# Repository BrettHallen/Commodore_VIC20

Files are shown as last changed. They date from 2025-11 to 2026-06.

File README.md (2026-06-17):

# Commodore VIC-20 Hardware Projects
Hardware &amp; information for the VIC-20.<br>

## [MFJ-1258 Capacitance Meter](/MFJ-1258/)
By MFJ Enterprises<br>

## [HAMSOFT Cartridge](/HAMSOFT/)
By Kantronics<br>

## [VIKTRAK+ Software & AUTOTRAK Cartridge](/VIKTRAK/)
By K7NH/Neil Hill<br>

## [6560/6561 A/V Breakout Board](/VIC_6560/) - UNTESTED
The VIC's default video output is pretty bad.  I've long wanted to "go back to basics" and see how the output can be improved by, for example, wiring it up as per its original datasheet example circuit.<br>

The first step is to create this breakout board to isolate the A/V signals from the video output stage on the VIC's motherboard.<br>

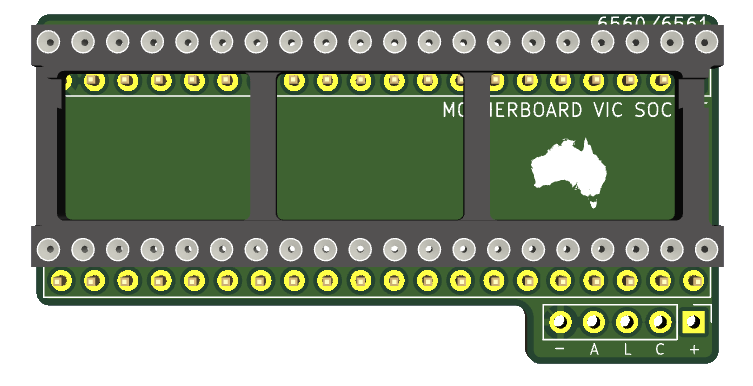
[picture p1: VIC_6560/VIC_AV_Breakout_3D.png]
3D view of breakout board


I hope that it will allow me to see what signals the 6560 outputs natively, then start to build on that.<br>

BTW, yes I know there are boards out there that already do this.  I've not had much luck with the free or paid-for boards, so I want to ... TRY TO ... understand it myself.  Let's see ...

## [6502 to W65C02S Daughterboard](/6502-to-65C02/) - UNTESTED
Unlike the 6522 VIAs that can be directly swapped for modern CMOS 65C22s from WDC, the W65C02S can't be directly swapped - a daughterboard is required to buffer the data bus signals and also handle some other signals/pins that differ.

3D view of 65C02S daughterboard

## [Serial Port Breakout Board for Logic Analysers](/Serial_Breakout_2)
I'm curious how JiffyDOS does its thing so whipped up a simple breakout board for the serial port so I can quickly and very easily connect up my logic analyser to capture the signalling with & without JiffyDOS.<br>

Connect the board to the VIC & the disc drive with a DIN-6, and then a 2x4 Dupont-style cable for the logic analyser.<br>

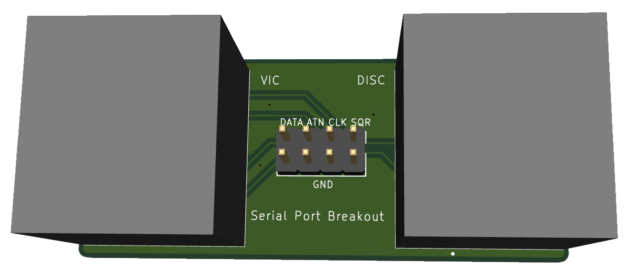
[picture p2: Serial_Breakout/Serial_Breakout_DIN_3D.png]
Serial breakout 3D


# RAM Expansions
Okay, my mind is full of ideas so it's probably a bit confusing with all these different designs.<br>

My original intent/idea was to replace the orignal ten 2114 RAM chips in case they were faulty.  It then grew from there.<br>

The different designs are:
- Original 8KB (BLK0) expansion: Replace the original 5KB plus 3KB expansion, switchable on/off via external switch.  This used a PLD which, in hindsight, is more complication than really needed.
- New 8KB expansion: Replace the PLD with the 74LS138, replicating the original VIC design but intercepting the ~RAM1/2/3 select signals.
- Simpler 8KB expansion: For a full BLK0 we really only need the ~BLK0 select signal so this greatly simplifies design but isn't switchable on/off.
- Full 32KB (BLK0/1/2/3) expansion
- Really Full 40KB (BLK0/1/2/3/5) expansion: Two designs to give the full 32+3KB expansion.  The Rev. A uses SMD and a larger SRAM and is, IMHO, overly complicated.  The Rev. B design is through-hole and piggybacks an 8KB (6264) SRAM on-top of the 32KB (62256) so we don't need to widen the board.

## [Orignal Internal 8KB RAM Expansion](/Internal_8KB/) - TESTED
My attempt to replace the VIC's built in 5KB of RAM (ten 2114 chips) with a single 8KB chip, with an extra 3KB RAM as a free bonus.

3D view of RAM upgrade board

## [New Internal 8KB RAM Expansion](/Internal_8KB_New/) - DESIGN
Removes the PLD and re-uses the 74LS138.

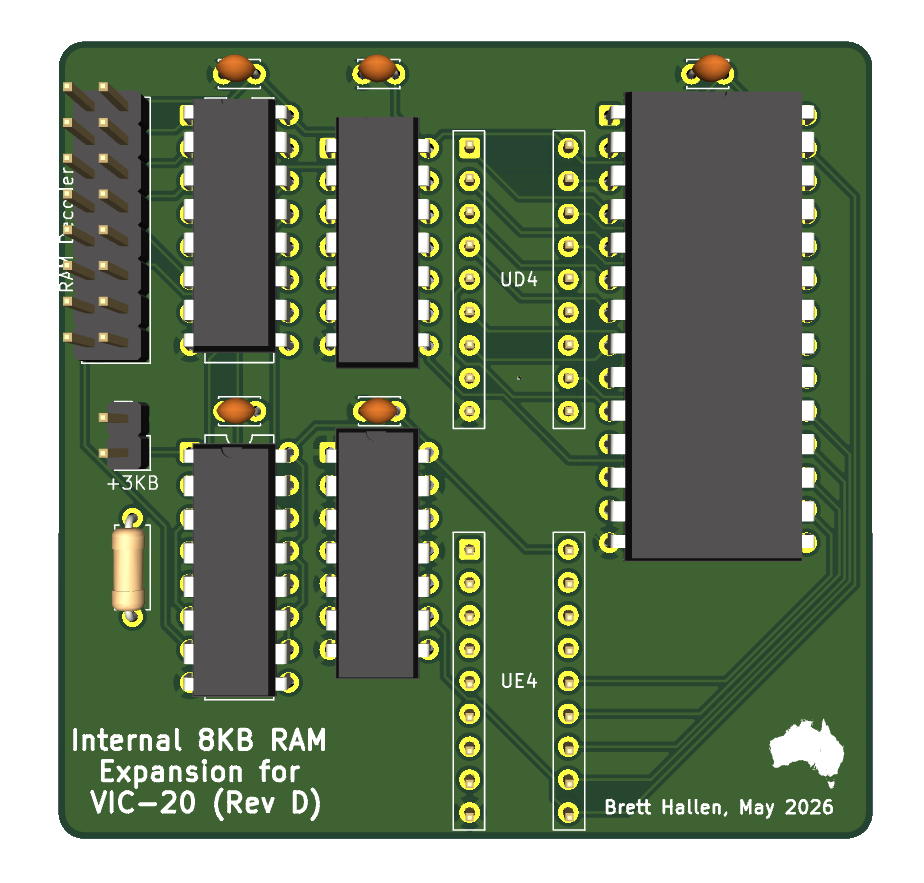
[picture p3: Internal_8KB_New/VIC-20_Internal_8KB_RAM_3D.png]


## [Simpler Internal 8KB RAM Expansion](/Internal_8KB_Simple/) - DESIGN
Just the 8KB for BLK0, nothing else.  As simple as my simple mind can make it.

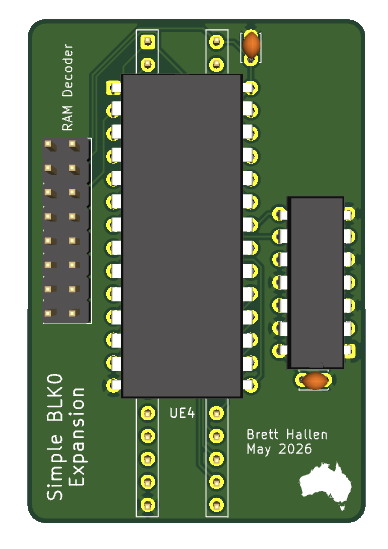
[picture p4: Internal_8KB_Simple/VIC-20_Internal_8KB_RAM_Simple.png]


## [Internal 40KB RAM Expansion](/Internal_40KB/) - DESIGNED
I've obsoleted the 32KB design and gone for this: the full 32KB of RAM in BLK0/1/2/3 plus an addition 8KB RAM or ROM in BLK5.<br>

The BLK1/2/3/5 are switchable off externally for software compatibility, and the BLK5 can be filled with either a 6264 SRAM or 2764/2864 (E)EPROM.  There is a header to switch whether it is writable (RAM) or not (ROM).<br>

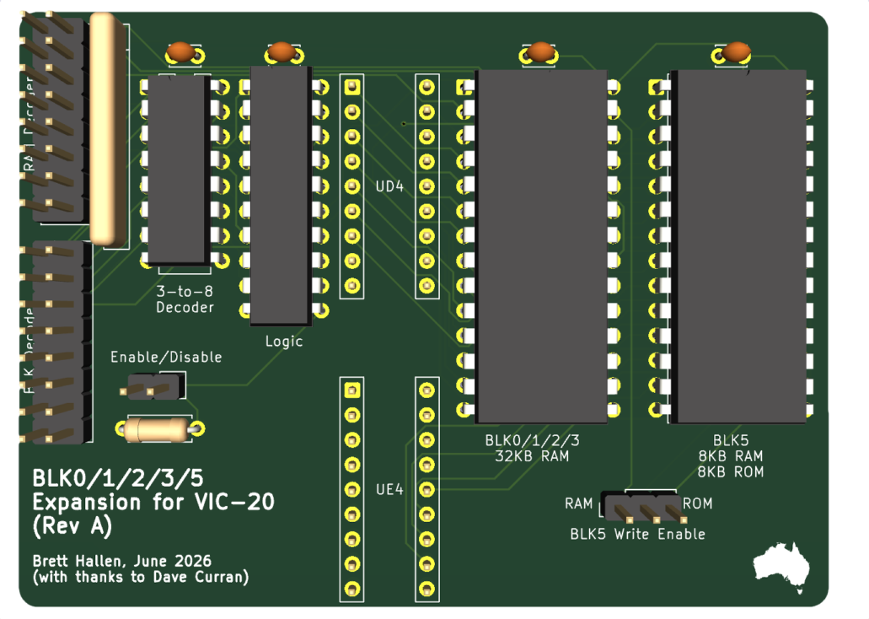
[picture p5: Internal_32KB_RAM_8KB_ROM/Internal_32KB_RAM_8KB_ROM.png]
The final boss of internal RAM expansions


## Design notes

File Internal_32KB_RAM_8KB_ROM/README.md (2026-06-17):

# Internal BLJK0/1/2/3/5 Expansion
My attempt to create a FAT VIC with a full 32KB internal RAM in BLK0/1/2/3 and an additioanl 8KB ROM or RAM in BLK5 without need for an external cartridge.<br>

Requires two [DIP-16 breakout boards](https://github.com/BrettHallen/Conversion_Boards/tree/main/DIP-16_Breakout) to replace the 74LS138 decoders.<br>

## Status
26-May-2026: complete re-design of my original idea, pending farbication & testing
17-Jun-2026: further re-design completed, pending fabrication & testing

## Purpose
- Save having to source replacement 2114 chips in case RAM is faulty;
- Upgrade the internal RAM unexpanded 5KB to a full 32KB, but switchable from outside the case depending on software requirements;
- Reduce power consumption/waste heat generation;
- Use as a learning experience to understand how the VIC's memory works and using a PLD;
- 100% reversible, no cutting of tracks required.

## YouTube Videos
- [Simple KiCad For Simple Vintage Computer Hobbyists: Part 5 (VIC-20 RAM Expansion)](https://youtu.be/WQpgBGNAkP0)
- [Commodore VIC-20 Internal RAM Replacement: Part 1](https://youtu.be/0KduuzFBmz8)
- [Commodore VIC-20 Internal RAM Replacement: Part 2](https://youtu.be/WdcPidc4c6I)

## Important Note
This information is provided to you completely free - use at your own risk.<br>
It is assumed that you kind-of know what you're doing - it is tricky removing chips from the VIC-20 motherboard as the top-layer tracks can lift up if there is still solder attached, so please be very careful.<br>
I've been using the Japanese-made ENGINEER SS-03 solder sucker a lot lately and highly recommend it.<br>

## Design
The VIC's memory is allocated in eight 8KB blocks named BLK0 to BLK7.  The RAM is normally found in BLK0 to BLK3.
```
Unexpanded VIC Memory
BLK0
0000   0000 0000 0000 0000 RAM0
03FF   0000 0011 1111 1111

1000   0001 0000 0000 0000 
1FFF   0001 1111 1111 1111 RAM4-7

Expanded VIC Memory
BLK0 (+3KB)
0400    0000 0100 0000 0000 RAM1
07FF    0000 0111 1111 1111

0800    0000 1000 0000 0000 RAM2
0BFF    0000 1011 1111 1111

0C00    0000 1100 0000 0000 RAM3
0FFF    0000 1111 1111 1111

BLK1 (+8KB)
2000    0010 0000 0000 0000
3FFF    0011 1111 1111 1111

BLK2 (+16KB)
4000    0100 0000 0000 0000
5FFF    0101 1111 1111 1111

BLK3 (+24KB)
6000    0110 0000 0000 0000
7FFF    0111 1111 1111 1111

BLK4 (Character ROM, VIC, VIAs, I/O, Colour RAM)
8000
9FFF

BLK5 (8KB ROM or RAM)
A000
BFFF

BLK6 (BASIC)
C000
DFFF

BLK7 (Kernal/Kernel)
E000
FFFF
```

[Commodore VIC-20 Memory Map](https://vic20reloaded.com/commodore-vic-20-memory-map/)

The daughterboard is designed to plug in to the VIC's motherboard where two of the original 2114 chips were located - expectation is that all ten 2114 chips are removed, and two replaced with an IC socket. <br>

The two 74LS138 decoders on the VIC motherboard are also removed and replaced with breakouts so the signals can be handled on the expansion daughterboard.<br>

### BLK0 Expansion
In order to fill in the missing 3KB in BLK0 we need to intercept the ~RAM1, ~RAM2 and ~RAM3 select signals and direct them to our RAM.<br>

This is done by relocating the 74LS138 to the expansion daughterboard and using all ~RAMx select signals for our RAM.<br>

### BLK1/2/3 Expansion
We should be able to fill in the BLK1/2/3 RAM by intercepting the associated ~BLK1, ~BLK2 and ~BLK3 select signals from the BLK decoder and using as the select signal for our RAM.<br>

Importantly we want to also be able to disable this additional RAM to allow software designed for the unexpanded/+3KB expanded VIC-20 to work correctly.  This can be done by connecting the ~BLK0/~BLK1/~BLK2 select signals via a multiplexor connected to an external switch that determines if the ~BLK1/2/3 select signals are passed back to the VIC or not.<br>

### BLK5 Expansion
This can have RAM or ROM, but the RAM isn't accessible from BASIC as it needs to be contiguous (BLK4 is in the way).  One possible use is to include the Super Expander ROM on the board.<br>

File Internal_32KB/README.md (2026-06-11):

# Internal 32KB RAM Expansion
My attempt to create a FAT VIC with a full 32KB internal RAM expansion without need for an external cartridge.<br>

Requires two [DIP-16 breakout boards](https://github.com/BrettHallen/Conversion_Boards/tree/main/DIP-16_Breakout) to replace the 74LS138 decoders.<br>

## Status
26-May-2026: complete re-design of my original idea, pending farbication & testing
11-Jun-2026: tested the re-design, it's "working" but has screen memory issues, fixed in next revision

## Purpose
- Save having to source replacement 2114 chips in case RAM is faulty;
- Upgrade the internal RAM unexpanded 5KB to a full 32KB, but switchable from outside the case depending on software requirements;
- Reduce power consumption/waste heat generation;
- Use as a learning experience to understand how the VIC's memory works and using a PLD;
- 100% reversible, no cutting of tracks required.

## YouTube Videos
- [Simple KiCad For Simple Vintage Computer Hobbyists: Part 5 (VIC-20 RAM Expansion)](https://youtu.be/WQpgBGNAkP0)
- [Commodore VIC-20 Internal RAM Replacement: Part 1](https://youtu.be/0KduuzFBmz8)
- [Commodore VIC-20 Internal RAM Replacement: Part 2](https://youtu.be/WdcPidc4c6I)

## Important Note
This information is provided to you completely free - use at your own risk.<br>
It is assumed that you kind-of know what you're doing - it is tricky removing chips from the VIC-20 motherboard as the top-layer tracks can lift up if there is still solder attached, so please be very careful.<br>
I've been using the Japanese-made ENGINEER SS-03 solder sucker a lot lately and highly recommend it.<br>

## Design
The VIC's memory is allocated in eight 8KB blocks named BLK0 to BLK7.  The RAM is normally found in BLK0 to BLK3.
```
Unexpanded VIC Memory
BLK0
0000   0000 0000 0000 0000 RAM0
03FF   0000 0011 1111 1111

1000   0001 0000 0000 0000 
1FFF   0001 1111 1111 1111 RAM4-7

Expanded VIC Memory
BLK0 (+3KB)
0400    0000 0100 0000 0000 RAM1
07FF    0000 0111 1111 1111

0800    0000 1000 0000 0000 RAM2
0BFF    0000 1011 1111 1111

0C00    0000 1100 0000 0000 RAM3
0FFF    0000 1111 1111 1111

BLK1 (+8KB)
2000    0010 0000 0000 0000
3FFF    0011 1111 1111 1111

BLK2 (+16KB)
4000    0100 0000 0000 0000
5FFF    0101 1111 1111 1111

BLK3 (+24KB)
6000    0110 0000 0000 0000
7FFF    0111 1111 1111 1111
```

[Commodore VIC-20 Memory Map](https://vic20reloaded.com/commodore-vic-20-memory-map/)

The daughterboard is designed to plug in to the VIC's motherboard where two of the original 2114 chips were located - expectation is that all ten 2114 chips are removed, and two replaced with an IC socket. <br>

The two 74LS138 decoders on the VIC motherboard are also removed and replaced with breakouts so the signals can be handled on the expansion daughterboard.<br>

### BLK0 Expansion
In order to fill in the missing 3KB in BLK0 we need to intercept the ~RAM1, ~RAM2 and ~RAM3 select signals and direct them to our RAM.<br>

This is done by relocating the 74LS138 to the expansion daughterboard and using all ~RAMx select signals for our RAM.<br>

### BLK1/2/3 Expansion
We should be able to fill in the BLK1/2/3 RAM by intercepting the associated ~BLK1, ~BLK2 and ~BLK3 select signals from the BLK decoder and using as the select signal for our RAM.<br>

Importantly we want to also be able to disable this additional RAM to allow software designed for the unexpanded/+3KB expanded VIC-20 to work correctly.  This can be done by connecting the ~BLK0/~BLK1/~BLK2 select signals via a multiplexor connected to an external switch that determines if the ~BLK1/2/3 select signals are passed back to the VIC or not.<br>

### CPU vs VIC RAM Access
The CPU (6502) and VIC (6560/6561) share access to the RAM, alternating depending on the state of the SΦ2 clock.  When the clock is high the CPU is accessing the RAM and when the clock is low it is the VIC's turn.<br>

Importantly the screen memory is in BLK0 and thus A13 and A14 are low.  My design failed to account for this and this results in the VIC accessing anywhere in the BLK0 to BLK3 range depending on what the status of A13 and A14 was.  I have improved the design to account for this, to be tested.

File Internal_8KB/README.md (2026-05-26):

# Internal 8KB RAM Expansion
My attempt to create a simple internal RAM upgrade board for the original VIC-20 (two-prong power, not the CR).  And, I'm not touching the single 2114 used for the colour RAM.<br>

## UPDATE 26-MAY-2026
I've [redesigned](/Internal_8KB_New) the 8KB expansion based on my 32KB design.<br>

## Purpose
- Save having to source replacement 2114 chips in case RAM is faulty;
- Upgrade the internal RAM from 5KB to 8KB, filling BLK0, but make it switchable ON/OFF from outside the case;
- Reduce power consumption/waste heat generation (reduced by just over 200mA, almost 20%);
- Use as a learning experience to understand how the VIC's memory works and using a PLD;
- 100% reversible, no cutting of tracks or soldering of wires to chip legs required.

## YouTube Videos
- [Simple KiCad For Simple Vintage Computer Hobbyists: Part 5 (VIC-20 RAM Expansion)](https://youtu.be/WQpgBGNAkP0)
- [Commodore VIC-20 Internal RAM Replacement: Part 1](https://youtu.be/0KduuzFBmz8)

## Important Note
This information is provided to you completely free - use at your own risk.<br>
It is assumed that you kind-of know what you're doing - it is tricky removing chips from the VIC-20 motherboard as the top-layer tracks can lift up if there is still solder attached, so please be very careful.<br>
I've been using the Japanese-made ENGINEER SS-03 solder sucker a lot lately and highly recommend it.<br>

## Design
This is the layout of the VIC's BLK0 (first 8KB chunk of memory):
```
1KB LOW (Zero Page)
0000-03FF   0000 0000 0000 0000 A10-A12 = 0
            0000 0011 1111 1111

3KB EXPANSION CARTRIDGE
0400-07FF   0000 0100 0000 0000 !RAM1  (A10)
            0000 0111 1111 1111
0800-0BFF   0000 1000 0000 0000 !RAM2  (A11)
            0000 1011 1111 1111
0C00-0FFF   0000 1100 0000 0000 !RAM3  (A10+A11)
            0000 1111 1111 1111

4KB MAIN
1000-1FFF   0001 0000 0000 0000 A12
            0001 0011 1111 1111 
            0001 0100 0000 0000 A10+A12
            0001 0111 1111 1111
            0001 1000 0000 0000 A11+A12
            0001 1011 1111 1111
            0001 1100 0000 0000 A10+A11+A12
            0001 1111 1111 1111
```

As per the existing VIC RAM design, we only want the RAM chip select to be active for these conditions:
- VA13 = high (when low the character ROM is selected), and
- BLK0 = low

All other combinations we want RAM chip select to be inactive.

Additionally, we want to be able to disable the full 8KB and return the VIC to its original "unexpanded VIC" state to avoid possible software compatibility issues.  The original 5KB of RAM is accessed when:
- A12 = high, or
- A10, A11, A12 = low

In its unexpanded state we should ignore all other combinations of A10 to A12.

The daughterboard is designed to plug in to the VIC's motherboard where two of the original 2114 chips were located - expectation is that all ten 2114 chips are removed, and two replaced with an IC socket.

The board itself is quite simple, using just the 6264 RAM chip and a PLD chip for the chip select logic.<br>

In order for the additional 3KB expansion to work we need to remove the 74LS138 RAM decoder (UC4 on my board) - its logic will be replaced by that in the PLD.<br>

Some wires need to be connected from the RAM board to where the [RAM decoder](/Internal_8KB/Images/VIC-20_internal_RAM_layout.jpg) was to pick up required signals:<br>
- VA10 from UC4 pin 1
- VA11 from UC4 pin 2
- VA12 from UC4 pin 3
- VA13 from UC4 pin 6
- /BLK0 from UC4 pin 4
- /RAM1 to UC4 pin 12
- /RAM2 to UC4 pin 13
- /RAM3 to UC4 pin 14

Note that all of these are connected using the additonal 74LS138 daughterboard.  Simply plug an 8-way cable set into the pin headers on the RAM and 74LS138 boards and the connections are done!<br>

## BOM
- 6264 SRAM
- GAL16V8 (i.e. Atmel F16V8B)
- 10KΩ pull-up resistor
- 2 x 100nF decoupling capacitor
- 2 x 18-pin DIP sockets (for UD4 & UE4 RAM locations)
- 4 x 9-pin SIL two-way pin headers (to plug into DIP sockets)
- 2 x 8-way pin header (for extra required signals)
- 2-way pin header (for 3KB expansion disable/enable)
- 1 x 16-pin DIP socket (for UC4 RAM decoder location)
- 8-way Dupont connector wiring

## Status
25-Apr-2025: Initial design done, checking-over before sending to PCBWAY for fabrication<br>
10-May-2025: Test PCB built & being tested<br>
11-May-2025: IT WORKS!  But, some small revisions to the board are required ...<br>
12-May-2025: Revisions to board made, new 74LS138 daughterboard created, might still tweak the design a little<br>
13-May-2025: I've decided to go all the way and create a 32KB expansion, still switchable from outside the case.<br>
15-May-2025: Sent revised 8KB and new 32KB boards for fabrication.<br>

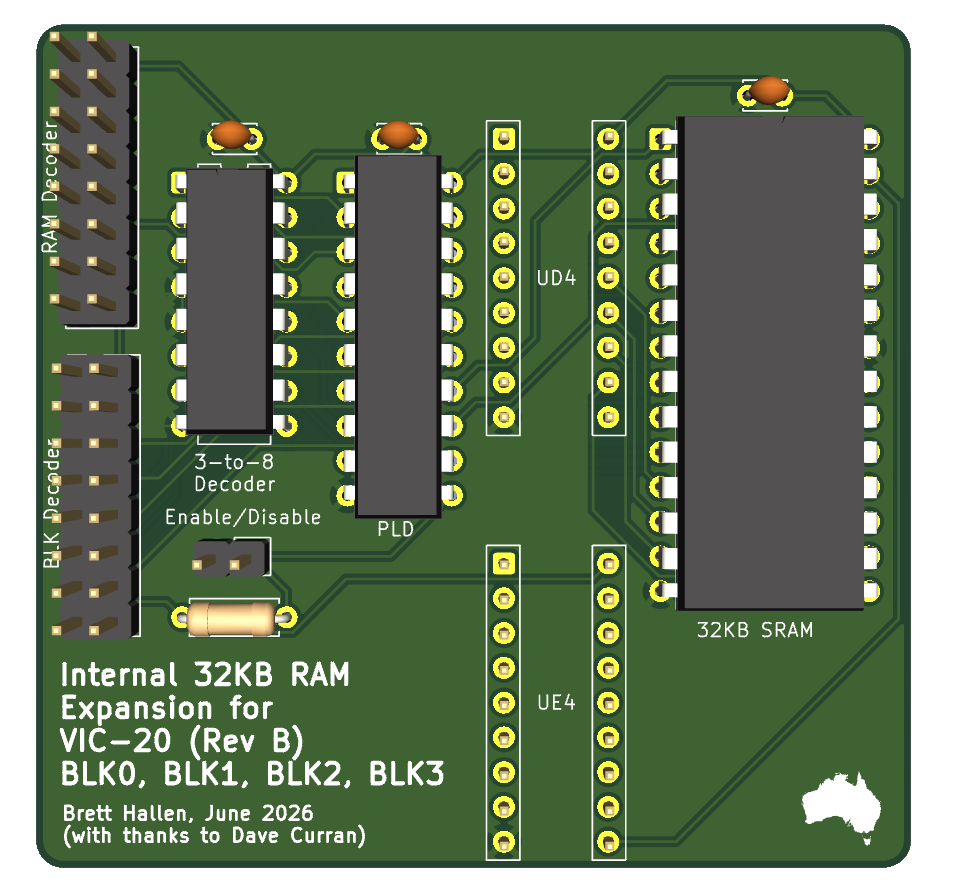
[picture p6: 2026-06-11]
Internal_32KB/VIC-20_Internal_32KB_3D.png

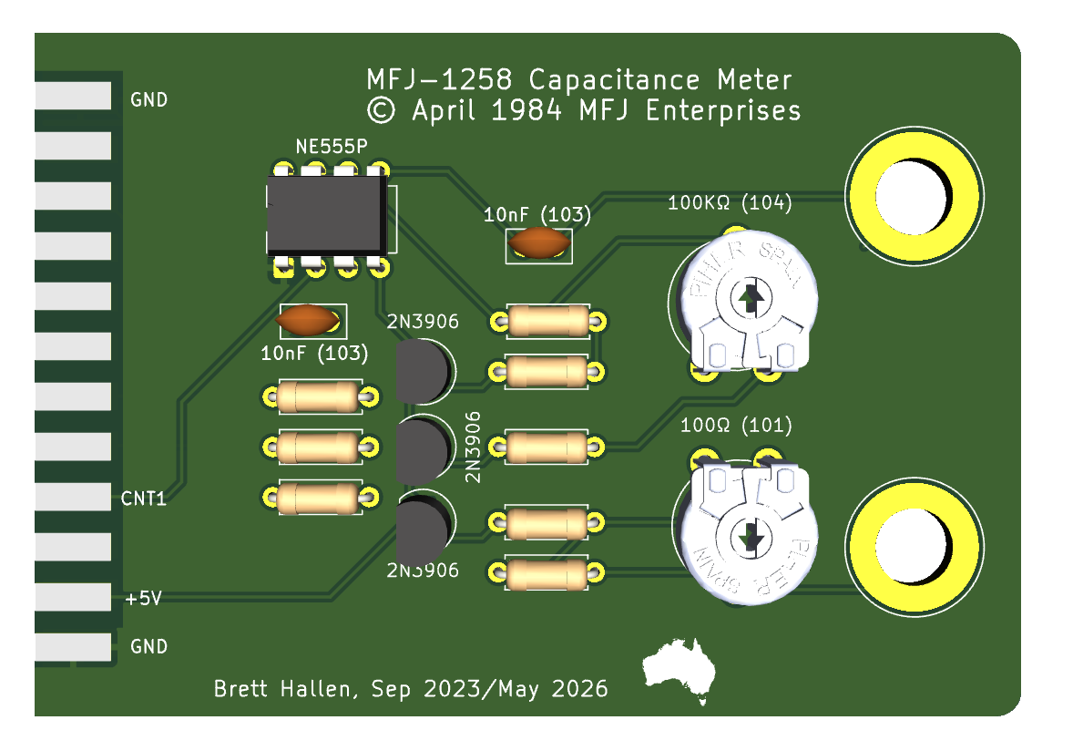
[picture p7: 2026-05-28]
MFJ-1258/Redrawn_MFJ-1258_Board.png

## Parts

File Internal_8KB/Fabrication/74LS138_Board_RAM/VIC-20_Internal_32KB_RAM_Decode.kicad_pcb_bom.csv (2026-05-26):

Designator | Quantity | Value | Footprint | Package | MPN | DNP | Mount_Type | Description
J1 | 1 | Signals | PinHeader_1x08_P2.54mm_Vertical |  |  |  | tht | Generic connector, single row, 01x08, script generated (kicad-library-utils/schlib/autogen/connector/)
UC4 | 1 | 74LS138 | DIP-16_W7.62mm |  |  |  | tht | Generic connector, double row, 02x08, counter clockwise pin numbering scheme (similar to DIP package numbering), script generated (kicad-library-utils/schlib/autogen/connector/)

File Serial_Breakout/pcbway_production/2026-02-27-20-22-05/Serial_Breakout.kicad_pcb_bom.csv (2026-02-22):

Designator | Quantity | Value | Footprint | Package | MPN | DNP | Mount_Type | Description | Height | Manufacturer_Name
J1 | 1 | VIC Serial In | 6710601 |  | 671-0601 |  | tht | Deltron 6 Pole Right Angle Din Socket Socket, 2A, 100 V ac, Lockable | 19.5 | DELTRON COMPONENTS
J2 | 1 | Disc Serial Out | 6710601 |  | 671-0601 |  | tht | Deltron 6 Pole Right Angle Din Socket Socket, 2A, 100 V ac, Lockable | 19.5 | DELTRON COMPONENTS
J3 | 1 | Breakout | PinHeader_2x04_P2.54mm_Vertical |  |  |  | tht | Generic connector, double row, 02x04, odd/even pin numbering scheme (row 1 odd numbers, row 2 even numbers), script generated (kicad-library-utils/schlib/autogen/connector/)

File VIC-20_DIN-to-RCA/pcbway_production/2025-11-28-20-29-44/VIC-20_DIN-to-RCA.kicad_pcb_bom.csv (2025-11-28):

Designator | Quantity | Value | Footprint | Package | MPN | DNP | Mount_Type | Description | Height | Manufacturer_Name | Mouser Part Number | Mouser Price/Stock
J1 | 1 | VIC-20 Composite | 6710801 |  | 671-0801 |  | tht | Deltron 8 Pole Right Angle Din Socket Socket, 2A, 100 V ac, Lockable | 19.5 | DELTRON COMPONENTS
J2 | 1 | RCA Video | FC68371 |  | FC68371 |  | tht | Socket; RCA; female; angled 90; THT; nickel plated; Marker: black | 14 | CLIFF ELECTRONIC COMPONENTS
J3 | 1 | Audio Out | SJ3350820BTR |  | SJ3-350820B-TR |  | tht | 3.5 mm Stereo Jack, Through Hole, 2 Conductors, 1 Internal Switches, Tape & Reel Packaging | 5.3 | Same Sky | 179-SJ3-350820B-TR | https://www.mouser.co.uk/ProductDetail/Same-Sky/SJ3-350820B-TR?qs=IKkN%2F947nfBCsohFK16iQg%3D%3D

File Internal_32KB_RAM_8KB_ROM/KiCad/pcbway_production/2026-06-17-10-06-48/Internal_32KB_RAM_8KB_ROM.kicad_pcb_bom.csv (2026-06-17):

Designator | Quantity | Value | Footprint | Package | MPN | DNP | Mount_Type | Description
C1, C2, C3, C4 | 4 | 100nF | C_Disc_D3.0mm_W2.0mm_P2.50mm |  |  |  | tht | Unpolarized capacitor
J1 | 1 | UD4 | DIP-18_W7.62mm |  |  |  | tht | Generic connector, double row, 02x09, counter clockwise pin numbering scheme (similar to DIP package numbering), script generated (kicad-library-utils/schlib/autogen/connector/)
J2 | 1 | UE4 | DIP-18_W7.62mm |  |  |  | tht | Generic connector, double row, 02x09, counter clockwise pin numbering scheme (similar to DIP package numbering), script generated (kicad-library-utils/schlib/autogen/connector/)
J3 | 1 | RAM Decoder | PinHeader_2x08_P2.54mm_Vertical |  |  |  | tht | Generic connector, double row, 02x08, counter clockwise pin numbering scheme (similar to DIP package numbering), script generated (kicad-library-utils/schlib/autogen/connector/)
J4 | 1 | BLK Decoder | PinHeader_2x08_P2.54mm_Vertical |  |  |  | tht | Generic connector, double row, 02x08, counter clockwise pin numbering scheme (similar to DIP package numbering), script generated (kicad-library-utils/schlib/autogen/connector/)
J5 | 1 | Disable/Enable Switch | PinHeader_1x02_P2.54mm_Vertical |  |  |  | tht | Generic connector, single row, 01x02, script generated (kicad-library-utils/schlib/autogen/connector/)
J6 | 1 | BLK5 Write Enable | PinHeader_1x03_P2.54mm_Vertical |  |  |  | tht | Generic connector, single row, 01x03, script generated (kicad-library-utils/schlib/autogen/connector/)
R1 | 1 | 10KΩ | R_Axial_DIN0207_L6.3mm_D2.5mm_P7.62mm_Horizontal |  |  |  | tht | Resistor
RN1 | 1 | 10KΩ | R_Array_SIP9 |  |  |  | tht | 8 resistor network, star topology, bussed resistors, small symbol
U1 | 1 | ATF16V8 | DIP-20_W7.62mm |  |  |  | tht | High-performance EE PLD, PAL Device Emulation / PAL Replacement, DIP-20
U2 | 1 | 74HCT138 | DIP-16_W7.62mm |  |  |  | tht | 3-to-8 line decoder/multiplexer inverting, DIP-16/SOIC-16/SSOP-16
U3 | 1 | 62256 | DIP-28_W15.24mm |  |  |  | tht | 32,768-word × 8-bit High Speed CMOS Static RAM, 70ns, DIP-28
U4 | 1 | 2864 | DIP-28_W15.24mm |  |  |  | tht | EEPROM 8K x 8, 5V, Not in Production, DIP-28

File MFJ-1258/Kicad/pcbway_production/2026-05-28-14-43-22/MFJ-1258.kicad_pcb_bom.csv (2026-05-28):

Designator | Quantity | Value | Footprint | Package | MPN | DNP | Mount_Type
C1, C2 | 2 | 10nF (103) | C_Disc_D5.0mm_W2.5mm_P2.50mm |  |  |  | tht
J1 | 1 | C64-UserPort | C64-User-Port-Female |  |  |  | smt
J2, J3 | 2 | Screw_Terminal_01x01 | Banana_Jack_1Pin |  |  |  | tht
Q1, Q2, Q3 | 3 | 2N3906 | TO-92_Inline |  |  |  | tht
R1 | 1 | 510Ω | R_Axial_DIN0207_L6.3mm_D2.5mm_P7.62mm_Horizontal |  |  |  | tht
R2 | 1 | 1.2MΩ | R_Axial_DIN0207_L6.3mm_D2.5mm_P7.62mm_Horizontal |  |  |  | tht
R3, R4, R5 | 3 | 4.7KΩ | R_Axial_DIN0207_L6.3mm_D2.5mm_P7.62mm_Horizontal |  |  |  | tht
R6 | 1 | 5.6MΩ | R_Axial_DIN0207_L6.3mm_D2.5mm_P7.62mm_Horizontal |  |  |  | tht
R7 | 1 | 3.9MΩ | R_Axial_DIN0207_L6.3mm_D2.5mm_P7.62mm_Horizontal |  |  |  | tht
R8 | 1 | 330Ω | R_Axial_DIN0207_L6.3mm_D2.5mm_P7.62mm_Horizontal |  |  |  | tht
RV1 | 1 | 100Ω (101) | Potentiometer_Piher_PT-10-V10_Vertical |  |  |  | tht
RV2 | 1 | 100KΩ (104) | Potentiometer_Piher_PT-10-V10_Vertical |  |  |  | tht
U1 | 1 | NE555P | DIP-8_W7.62mm |  |  |  | tht

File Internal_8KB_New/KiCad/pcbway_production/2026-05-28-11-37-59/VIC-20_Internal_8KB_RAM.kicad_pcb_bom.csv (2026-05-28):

Designator | Quantity | Value | Footprint | Package | MPN | DNP | Mount_Type | Description
C1, C2, C3, C4, C5 | 5 | 100nF | C_Disc_D3.0mm_W2.0mm_P2.50mm |  |  |  | tht | Unpolarized capacitor
J1 | 1 | RAM Decoder | PinHeader_2x08_P2.54mm_Vertical |  |  |  | tht | Generic connector, double row, 02x08, counter clockwise pin numbering scheme (similar to DIP package numbering), script generated (kicad-library-utils/schlib/autogen/connector/)
J2 | 1 | UD4 | DIP-18_W7.62mm |  |  |  | tht | Generic connector, double row, 02x09, counter clockwise pin numbering scheme (similar to DIP package numbering), script generated (kicad-library-utils/schlib/autogen/connector/)
J3 | 1 | UE4 | DIP-18_W7.62mm |  |  |  | tht | Generic connector, double row, 02x09, counter clockwise pin numbering scheme (similar to DIP package numbering), script generated (kicad-library-utils/schlib/autogen/connector/)
J4 | 1 | +3KB | PinHeader_1x02_P2.54mm_Vertical |  |  |  | tht | Generic connector, single row, 01x02, script generated (kicad-library-utils/schlib/autogen/connector/)
R1 | 1 | 10KΩ | R_Axial_DIN0207_L6.3mm_D2.5mm_P7.62mm_Horizontal |  |  |  | tht | Resistor
U1 | 1 | 74HCT04 | DIP-14_W7.62mm |  |  |  | tht | Hex Inverter
U2 | 1 | 74HCT138 | DIP-16_W7.62mm |  |  |  | tht | Decoder 3 to 8 active low outputs
U3 | 1 | 74HCT30 | DIP-14_W7.62mm |  |  |  | tht | 8-input NAND
U4 | 1 | 74HCT157 | DIP-16_W7.62mm |  |  |  | tht | Quad 2 to 1 line Multiplexer
U5 | 1 | 6264 SRAM | DIP-28_W15.24mm |  |  |  | tht | Not in Production, 8Kx8 bit Static RAM, 70/85/100/120/150ns, DIP-28

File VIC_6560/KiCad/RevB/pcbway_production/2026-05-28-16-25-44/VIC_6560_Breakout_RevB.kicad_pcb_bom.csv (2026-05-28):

Designator | Quantity | Value | Footprint | Package | MPN | DNP | Mount_Type | Description
J1 | 1 | MOTHERBOARD VIC SOCKET | DIP-40_W15.24mm |  |  |  | tht | Generic connector, double row, 02x20, counter clockwise pin numbering scheme (similar to DIP package numbering), script generated (kicad-library-utils/schlib/autogen/connector/)
J2 | 1 | BREAKOUT_PINS | PinHeader_1x05_P2.54mm_Vertical |  |  |  | tht | Generic connector, single row, 01x05, script generated (kicad-library-utils/schlib/autogen/connector/)
U1 | 1 | 6560/6561 | DIP-40_W15.24mm |  |  |  | tht

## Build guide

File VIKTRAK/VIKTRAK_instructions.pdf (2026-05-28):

VIKTRAK+ DISTRIBUTED BY | Retyped by
SPECTRUM WEST | Brett Hallen, Nov 2024
?717 N.E. 56th | YouTube.com/@Brfff
Seattle, WA 98150

VIKTRAK+ is a satellite tracking program for the VIC20 with three or more kilobytes of additional memory (see note 1),

MAIN FEATURES
1. This program is easy to use, fast, and colourful.
2. Handles both elliptical and circular satellites.
3. Provides satellite location with a blinking cursor on a World Map.
Provides bearing and elevation to satellite if it is within range.
4. Output to a printer is provided for hardcopy of data.
5. A software routine is built in to operate an automatic antenna aiming system.

STARTING OUT
"LOAD” the program into the computer using normal tape loading procedure. The program starts at 5 on the tape counter and takes about two minutes. A second copy of the program is at 50 on the counter.

After the tape is loaded you need to put in your home latitude (HT) and home Longitude (HN). Type in LIST 150 and press RETURN. Use normal VIC editing techniques to enter your latitude and longitude. At this time it would be wise to get a clean cassette and make an operating copy of this program. To do so enter RUN and press RETURN. A MENU will appear. Press “D” (SAVE PGM) and start recording on your clean cassette. Take the original cassette of VIKTRAK+ and put it in a safe place as a permanent backup copy. If you hate to read instructions, now is the time to put this aside and play with the program. Just follow screen instructions. If you should drop out of the program just enter RUN and press RETURN to get back to the MENU.

HOW TO USE THE PROGRAM
The MENU gives you four choices. The main section, “Tracking,” is entered by pressing “A”. Next will follow three requests. First enter the date you desire, using the example, incorrect format cannot be processed so a “?” will appear meaning try again. Next you will be asked which satellite you want. A list of satellites available is provided on the screen. The program will only accept these as choices, otherwise a “?” will appear. Lastly the UTC time will be asked for. Times from 0000 to 2359 UTC will be accepted, otherwise the “?” will appear again. When these three requests are fulfilled a World Map will be drawn on the screen with a blinking cursor showing satellite location, name of satellite, date, time, satellite longitude and latitude will also be shown, as well as bearing and elevation IF the satellite is within range. Orbit PHASE is included for elliptical satellites. The program is designed to run in real time, updating itself each six minutes for elliptical satellites and two minutes for circular ones. Manual updating can be accomplished by pressing RETURN as often as you desire. Several choices are available at this time if so desired and are noted at the top of the screen. Here is how they work.
A=AOS will cause the program to leave real time and calculate the next Acquisition of Signal time. It may take a while, so relax. The length of time depends on which satellite is being tracked and how long it is to AOS.

N=NEW SAT allows you to switch satellites at will. You will be asked for what UTC time you desire for this new satellite.
M=MENU returns you to the start of the program. You should do this whenever you want to change dates.
T=TIME lets you change UTC time at will. The new data will appear in about two seconds.
P=PRINTER allows the screen data to be output to a printer. In this mode real time is bypassed and your printer will give new update information every five seconds or so. To exit this mode press “P” again right after a line is printed, it will revert to normal tracking mode.

One thing about the program should be noted. You can proceed into a new day and the date will change but if a new UTC time is requested the resulting data will be for the original date selected. Remember, return to the MENU whenever a new date is desired unless you leave the program in the automatic update mode.

Back to the menu choices:
Pressing “B” allows you to easily change satellite data. You will be asked for which satellite you want data. After entering this the program lines containing that satellite data will be listed on the screen. This data can be changed by the normal screen editing of the VIC20. Return to the MENY by entering RUN and pressing RETURN. Don’t forget to move the cursor out of the listing area before entering RUN as you may modify the program lines accidentally.
Pressing “C” brings up a screen page of frequency information for satellites available in the program.
Selecting “D” allows a quick and easy way to RESAVE the program after any data has been changed. Please don’t use this to make extra copies of this program for your friends. The program is copyrighted and besides the price is very reasonable. Telling them where to send for the program would be a honest help for your friends.

SATELLITE DATA UPDATES
This program uses a somewhat non-standard set of data to computer satellite location but this information is readily available from several sources such as WIAW bulletins, NASA, AMSAT nets, and AMATEUR SATELLITE REPORT published by AMSAT.

The first three numbers needed pertain to reference orbit information. A reference orbit is the first orbit of whatever reference day you choose.
DR is Day of Reference and is the day of the year. DR can be calculated by using the tracking program. When asked for the date you desire, enter the date of your reference data. Example: 04APR84. When the program ask for satellite name press RUN/STOP and RESTORE together. You will exit the program (and change screen colour). Now enter PRINT DY, and press RETURN. The number that appears is DR (Day Reference).
MR is Minutes of Reference. It is the time of apogee (for elliptical satellites) or equator crossing (for circular satellites) and is entered in minutes and tenths of minutes, example: 2 hrs 10 mins and 30 secs would be 130.5 minutes.
LR is Longitude Reference and is always west longitude. If a reference is given as east longitude just subtract it from 360. Example: 15 degrees east longitude would be 360-15, or 345 degrees west longitude.
Remember: DR is Day of Year, MR is in minutes, and LR is always in longitude west.

Elliptical satellites use first apogee for Reference Day, circular satellites use first EQX crossing of Reference Day.

There are six other pieces of data still needed - these are the Keplerian or orbital elements. They are:
PE - Nodal Period
LI - Longitude Increment West
W - Argument of Perigee (zero for circular satellites) I - Inclination
SE - Semimajor Axis
EC - Eccentricity

This information is available from AMATEUR SATELLITE REPORT, AMSAT nets (Tuesday, 8:00pm local, 3850 kHz) or NASA. Of these only one needs to be updated except rarely. Once a month or so for elliptical satellites update W (Argument of Perigee). At the same time put in new reference orbit data for those satellites you’re using. This should be often enough.

TO ADD NEW SATELLITES
As more satellites are put up you will want to add them to this program. A standard layout is used to store data. LIST 650-658 to see the layout for circular satellites, or LIST 800-894 for elliptical satellites. Use these as a pattern.

650 ON-(N$<>"RS5") GOTO 660:IF M$="B"THEN LIST 652-656
652 W=0:I=82.96:SE=8034:EC=0
654 PE=119.554:LI=30.02
656 DR=346:MR=16.4:LR=236.4
658 RETURN

800 ON-(N$<>"O10") GOTO 620:IF M$="B" THEN LIST802-806 802 I=26.35:SE=26106:EC=.597
804 PE=699.45:LI=175.42
806 DR=334:MR=582:LR=225:W=65
808 GOTO 890
890 MR=MR-PE/2:LR=LR+(360-LI)/2:IF MR<0 THEN MR=MR+PE:LR=LR+LI
892 IF LR>=360 THEN LR=LR-360
894 RETURN

Note lines 980-984 are needed to convert apogee data to the perigee data used by the program for elliptical satellites. These lines are not needed for circular satellites as perigee is set on the equator when W is zero. Don’t forget to add your new satellites name to line 610.

AUTOROTOR is a software routine designed to work into a plug-in board to interface with appropriate rotators for automatic antenna aiming. These boards should be available soon.

Any comments and/or suggestions would be appreciated. See you on the birds.

Note: 1. This program comes set up for 8K or more of extra memory. It can be used with 3K memory by making these changes:
Line 43, change 4404 to 7988
Line 44, change 33792 to 30720

43 U%=4404-INT((U+50)/10)*22:S%=S%+U%
44 POKE S%,96:POKE S%+33792,1:FOR L=1 TO 9:GET A$:ON-(A$<>"") GOTO 54:NEXT

FURTHER INFORMATION [NOV 2024] https://www.spaceacademy.net.au/watch/track/orbspec.htm

The position of an orbital space object can thus be specified by six parameters:
1. a - the semimajor axis specifies the size of the orbit
2. e - the eccentricity specifies the shape of the orbit
3. i - the inclination specifies one orientation of the orbit
4. ω - the argument of perigee specifies a 2nd orientation of the orbit
5. Ω - the argument of the ascending node specifies the 3rd oreientation
6. tp - the time of perigee passage is used to calculate the object location in the orbit

These parameters are sometimes referred to as the Keplerian elements of the orbit.

However, they are not the only way to specify the position of an object.

The US Strategic Command, which operates the US space tracking network issues space object orbital information in a form they call TLE (Two Line Elements) because the specified parameters are printed over two lines.

The actual six parameters used are a modification of the six elements we have used previously.

- n - the mean motion of the satellite in revolutions per day (this gives a)
- e - the orbital eccentricity (identical)
- i - the orbital inclination (identical)
- RAAN - the Right Ascension of the Ascending Node (this gives Ω)
- ω - the argument of perigee (identical)
- M - the mean anomaly at the time specified in the TLE and substitutes for the tp parameter
- D/T - date and time of the TLE

There is also a decay value included - which refers to orbital change due to atmospheric perturbation of the elements.

To calculate the satellite mean anomaly you subtract the the TLE time from the satellite prediction time and multiply the result by the mean motion n.

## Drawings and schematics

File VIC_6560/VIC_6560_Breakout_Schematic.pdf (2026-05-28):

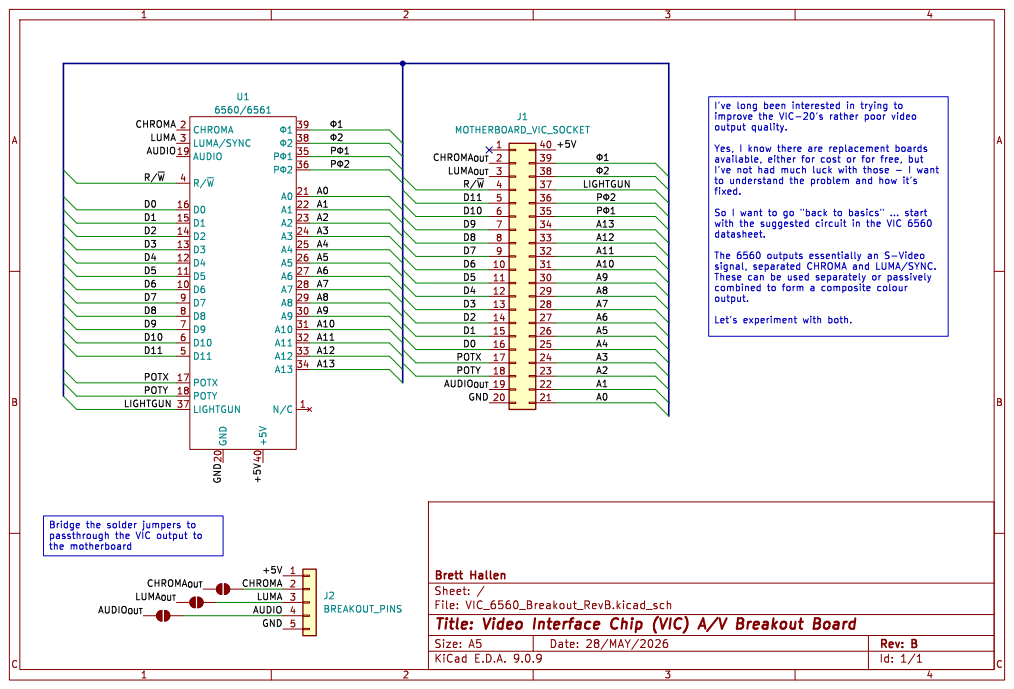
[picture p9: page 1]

I've not had much luck with those - I want
fixed.

Bridge the solder jumpers to
the motherboard

Sheet: /
File: VIC_6560_Breakout_RevB.kicad_sch
Title: Video Interface Chip (VIC) A/V Breakout Board

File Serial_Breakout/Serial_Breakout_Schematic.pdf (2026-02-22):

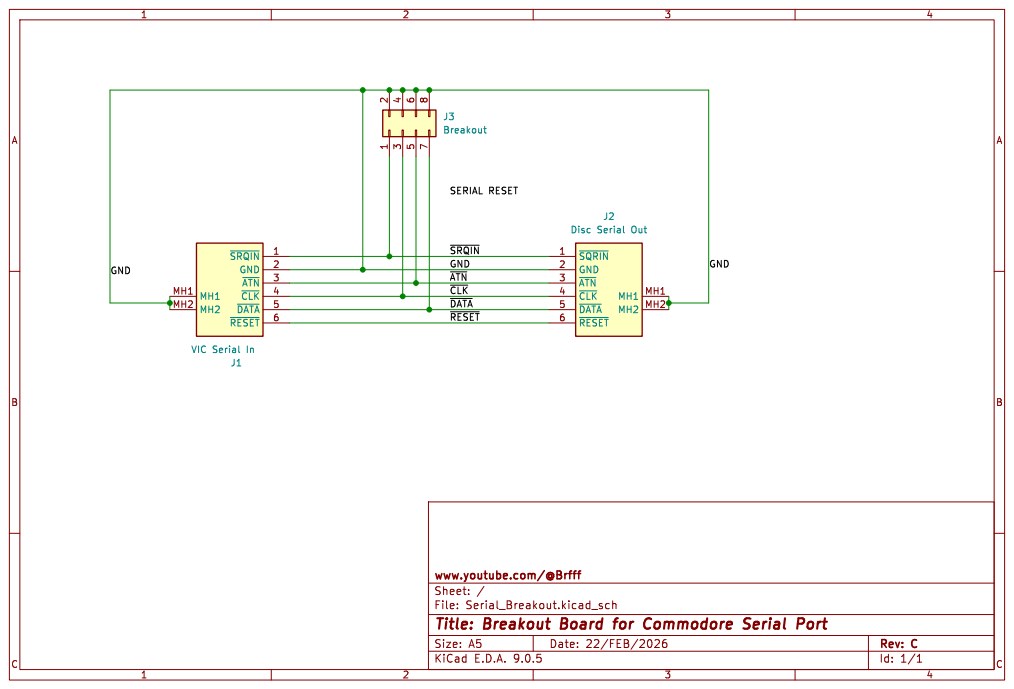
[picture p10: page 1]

GND | | GND 2 GND GND

~{ATN} | | ~{ATN} 3
~{CLK} | | ~{CLK} 4

www.youtube.com/@Brfff
Sheet: /
File: Serial_Breakout.kicad_sch
Title: Breakout Board for Commodore Serial Port

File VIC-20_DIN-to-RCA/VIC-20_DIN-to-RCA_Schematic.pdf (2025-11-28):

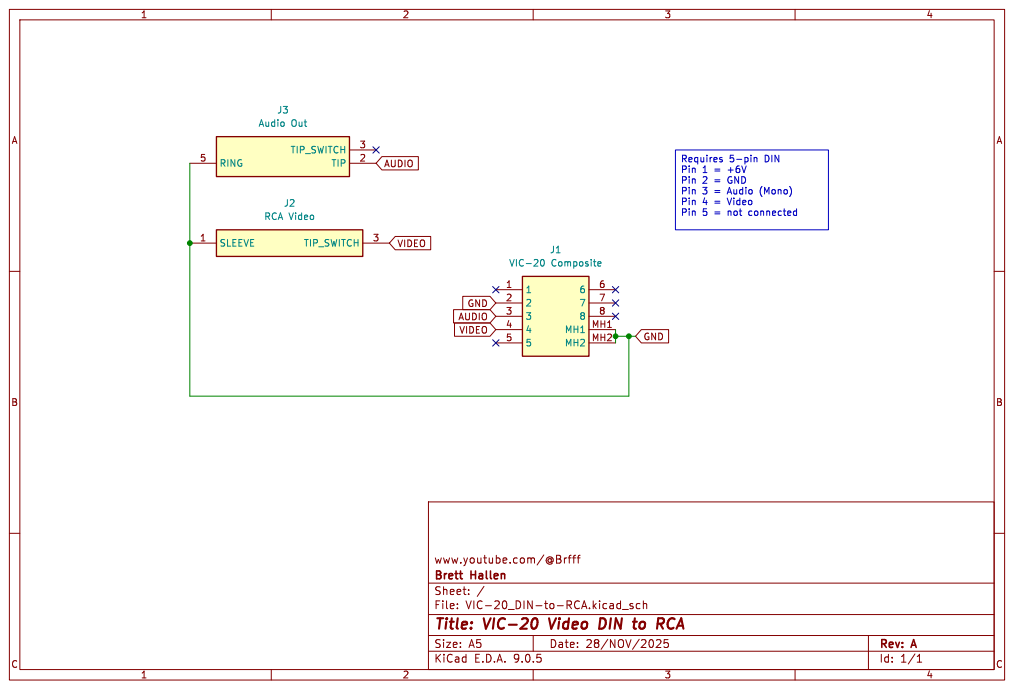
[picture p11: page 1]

www.youtube.com/@Brfff
Sheet: /
File: VIC-20_DIN-to-RCA.kicad_sch

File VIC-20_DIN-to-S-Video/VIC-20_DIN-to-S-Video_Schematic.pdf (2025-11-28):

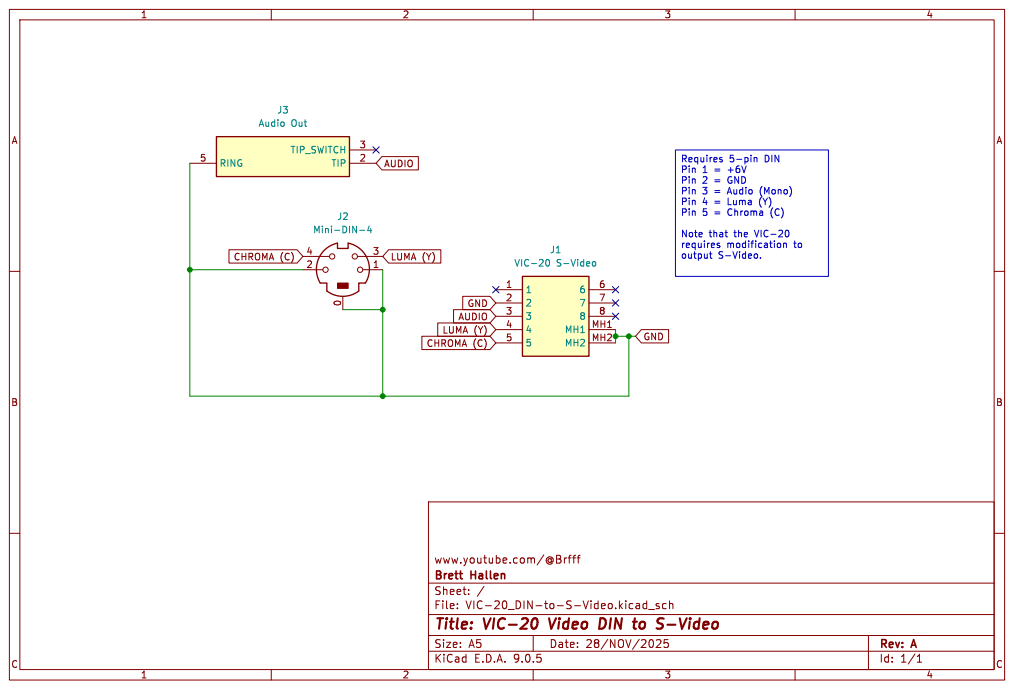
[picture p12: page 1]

www.youtube.com/@Brfff
Sheet: /
File: VIC-20_DIN-to-S-Video.kicad_sch

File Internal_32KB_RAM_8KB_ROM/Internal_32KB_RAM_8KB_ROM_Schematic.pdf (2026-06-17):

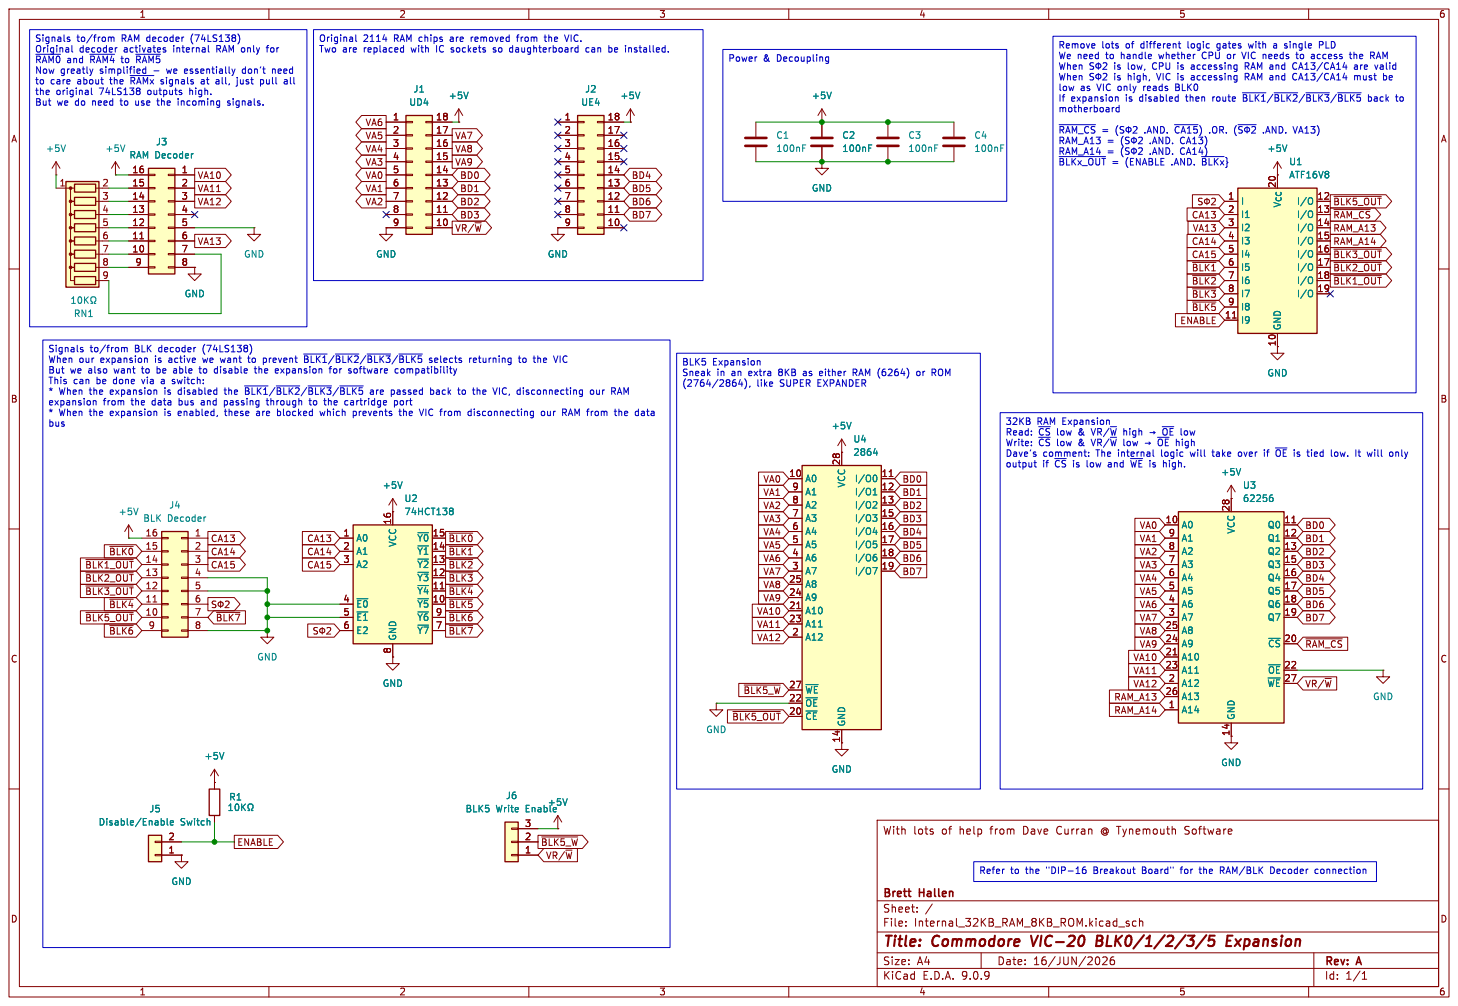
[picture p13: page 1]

low as VIC only reads BLK0

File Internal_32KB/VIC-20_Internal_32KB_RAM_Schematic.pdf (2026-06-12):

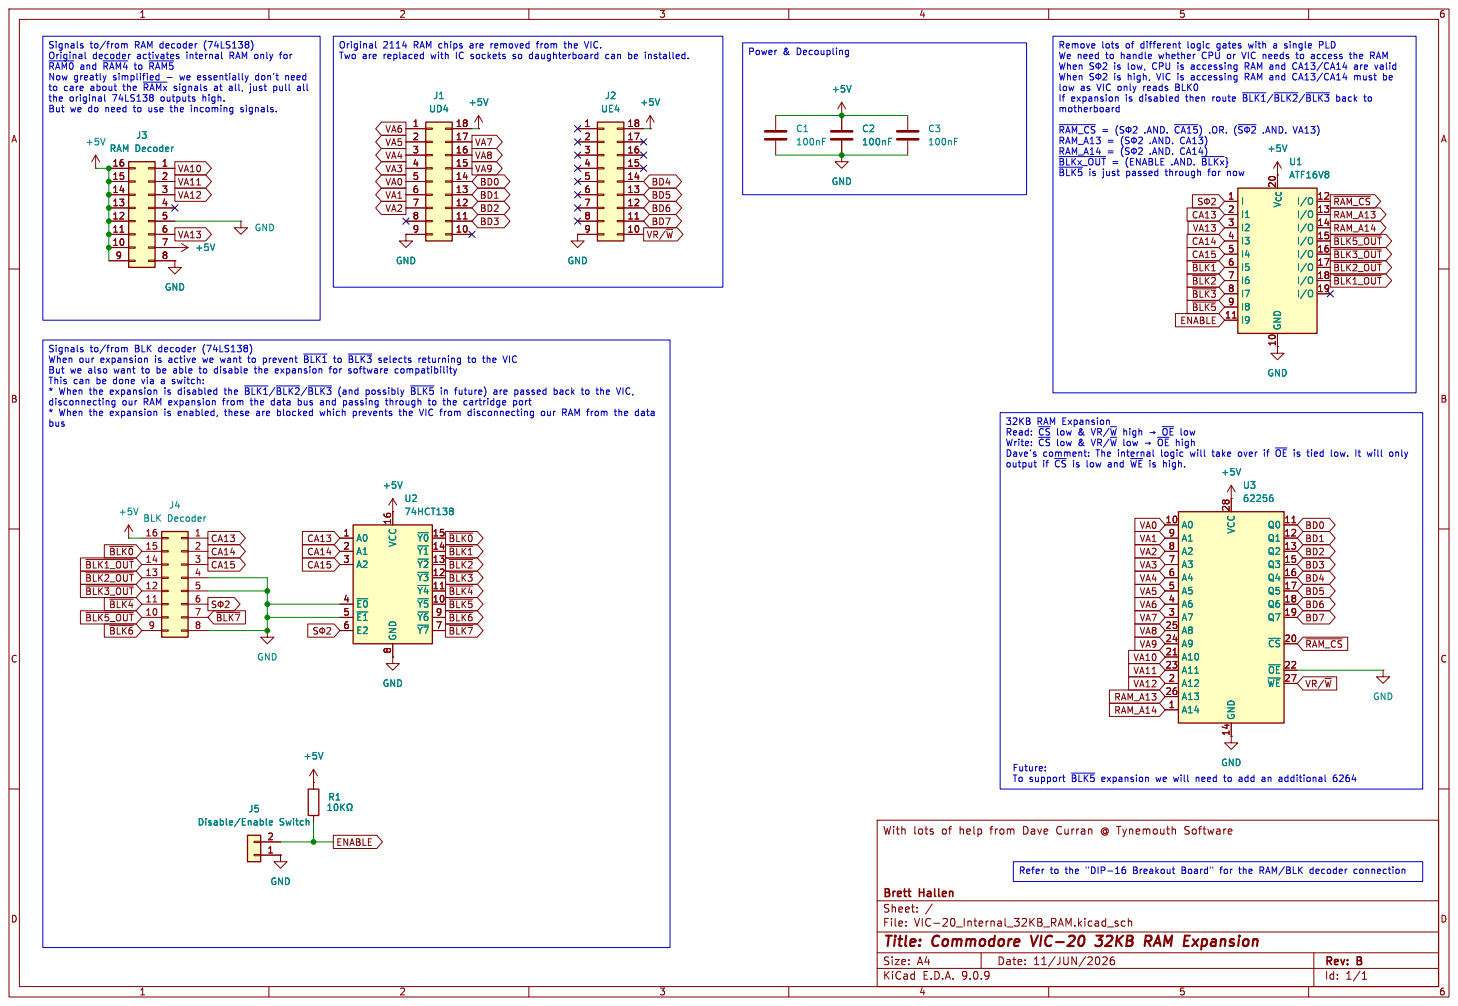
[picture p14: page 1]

low as VIC only reads BLK0

~{BLKx_OUT}= (ENABLE .AND. ~{BLKx}}
~{BLK5}is just passed through for now

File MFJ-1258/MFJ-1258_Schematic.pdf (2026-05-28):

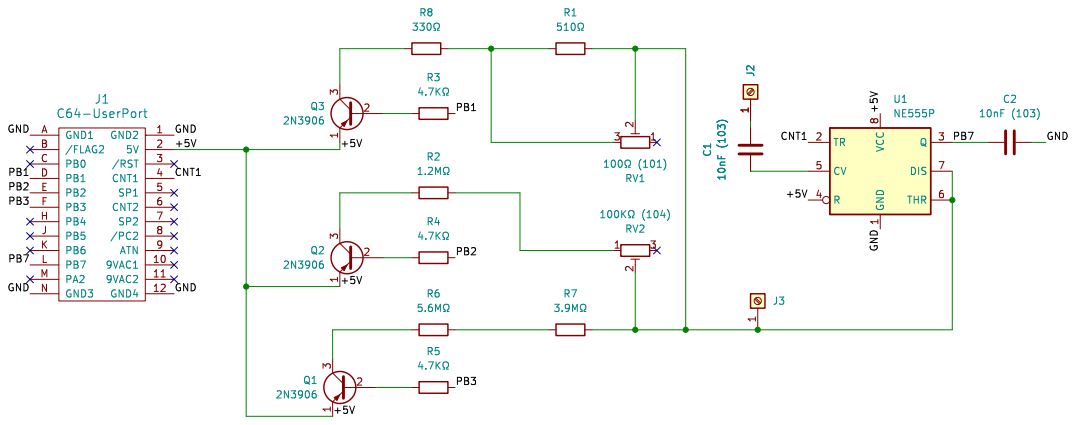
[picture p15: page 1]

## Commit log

2026-02-22 Corrected pinout
    [Serial_Breakout.kicad_pcb, Serial_Breakout.kicad_pcb_bom.csv, Serial_Breakout.kicad_pcb_positions.csv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]
2026-05-26 Complete redesign
    [VIC20_Internal_32KB_BLK_Decode.kicad_pcb, VIC20_Internal_32KB_BLK_Decode.kicad_pcb_bom.csv, VIC20_Internal_32KB_BLK_Decode.kicad_pcb_positions.csv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]
2026-05-26 Redesigned 32KB expansion
    [DIP-16_Breakout.kicad_pcb, DIP-16_Breakout.kicad_pcb_bom.csv, DIP-16_Breakout.kicad_pcb_positions.csv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]
2026-05-26 Silkscreen improvements
    [DIP-16_Breakout.kicad_pcb, DIP-16_Breakout.kicad_pcb_bom.csv, DIP-16_Breakout.kicad_pcb_positions.csv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]
2026-05-26 Removed DIP-16 breakout
    Refer to the Conversion_Boards repo for the design
    [DIP-16_Breakout.kicad_pcb, DIP-16_Breakout.kicad_pcb_bom.csv, DIP-16_Breakout.kicad_pcb_positions.csv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]
2026-05-26 Re-designed 8KB expansion
    [VIC20_Internal_8KB_RAM.kicad_pcb, VIC20_Internal_8KB_RAM.kicad_pcb_bom.csv, VIC20_Internal_8KB_RAM.kicad_pcb_positions.csv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]
2026-05-26 Work started, in progress
    [VIC-20_Internal_40KB_RAM.kicad_pcb, VIC-20_Internal_40KB_RAM.kicad_sch]
2026-05-27 Swapped 62256 -> 6264
    [VIC-20_Internal_8KB_RAM.kicad_pcb, VIC-20_Internal_8KB_RAM.kicad_pcb_bom.csv, VIC-20_Internal_8KB_RAM.kicad_pcb_positions.csv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]
2026-05-27 Initial design completed
    [VIC-20_Internal_40KB_RAM.kicad_pcb, VIC-20_Internal_40KB_RAM.kicad_pcb_bom.csv, VIC-20_Internal_40KB_RAM.kicad_pcb_positions.csv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]
2026-05-27 Moved to RevA folder, started RevB design
    [VIC-20_Internal_32KB_RAM.kicad_pcb_bom.csv, VIC-20_Internal_32KB_RAM.kicad_pcb_positions.csv, VIC-20_Internal_40KB_RAM.kicad_pcb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]
2026-05-27 Initial Rev B design
    A simple extension of the 32KB expansion by adding a 6264 piggybacked on top of the 62256 and routing the ~BLK5 select to it.
    [VIC-20_Internal_40KB_RAM_RevB.kicad_pcb, VIC-20_Internal_40KB_RAM_RevB.kicad_pcb_bom.csv, VIC-20_Internal_40KB_RAM_RevB.kicad_pcb_positions.csv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]
2026-05-27 Added +3KB disable switch
    [VIC-20_Internal_40KB_RAM_RevB.kicad_pcb, VIC-20_Internal_40KB_RAM_RevB.kicad_pcb_bom.csv, VIC-20_Internal_40KB_RAM_RevB.kicad_pcb_positions.csv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]
2026-05-28 Initial commit
    Simplest idea for a BLK0 (+3KB) expansion - simply hook a 6264 SRAM up to the ~BLK0 select signal (that would be used by the 74LS138 RAM decoder) as the 6264 ~CS
    Seemed a bit pointless using a 3-to-8 decoder (74LS138) to generate all of the ~RAMx select signals when I then just combined them into a single ~CS for the 6264
    Instead, use the ~BLK0 select signal that was used as the active low enable to the 74LS138 as the RAM's ~CS
    Then just need an inverter to generate the RAM ~OE from the VR/W read/write signal (R=read, ~W=write, ~OE=active only when reading)
    [VIC-20_Internal_8KB_RAM_Simple.kicad_pcb, VIC-20_Internal_8KB_RAM_Simple.kicad_pcb_bom.csv, VIC-20_Internal_8KB_RAM_Simple.kicad_pcb_positions.csv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]
2026-05-28 Revised BLK0 expansion
    Added enable/disable function to return VIC to unexpanded 5KB state
    ~RAM1/~RAM2/~RAM3 select signals routed back to VIC when disabled
    [VIC-20_Internal_8KB_RAM.kicad_pcb, VIC-20_Internal_8KB_RAM.kicad_pcb_bom.csv, VIC-20_Internal_8KB_RAM.kicad_pcb_positions.csv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]
2026-05-28 Re-layout/Re-draw PCB
    A few years more experience using KiCad now, updated from KiCad 6 to KiCad 9
    [MFJ-1258.kicad_pcb, MFJ-1258.kicad_pcb_bom.csv, MFJ-1258.kicad_pcb_positions.csv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]
2026-05-28 Cleaning up designs
    Keeping just the DIN-to-DIN breakout
    [Serial_Breakout.kicad_pcb, Serial_Breakout.kicad_pcb_bom.csv, Serial_Breakout.kicad_pcb_positions.csv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]
2026-05-28 Created RevB
    Redesigned PCB so it might (?) fit on the motherboard when the RF shielding is still in place
    [VIC_6560_Breakout.kicad_pcb, VIC_6560_Breakout.kicad_sch, VIC_6560_Breakout_RevB.kicad_pcb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]
2026-06-11 Further design corrections
    [VIC-20_Internal_32KB_RAM.kicad_pcb, VIC-20_Internal_32KB_RAM.kicad_pcb_bom.csv, VIC-20_Internal_32KB_RAM.kicad_pcb_positions.csv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]
2026-06-17 Finalised 40KB design for testing
    [Internal_32KB_RAM_8KB_ROM.kicad_pcb, Internal_32KB_RAM_8KB_ROM.kicad_pcb_bom.csv, Internal_32KB_RAM_8KB_ROM.kicad_pcb_positions.csv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]
